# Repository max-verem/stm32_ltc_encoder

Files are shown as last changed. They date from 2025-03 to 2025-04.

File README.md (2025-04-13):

# stm32_ltc_encoder

This device used for decoding/encoding LTC (EBU Linear timecode) from/to VTRs or other sources.

Decoded Output sent to CDC serial. Encoding control cli available on second CDC serial.

## schematic

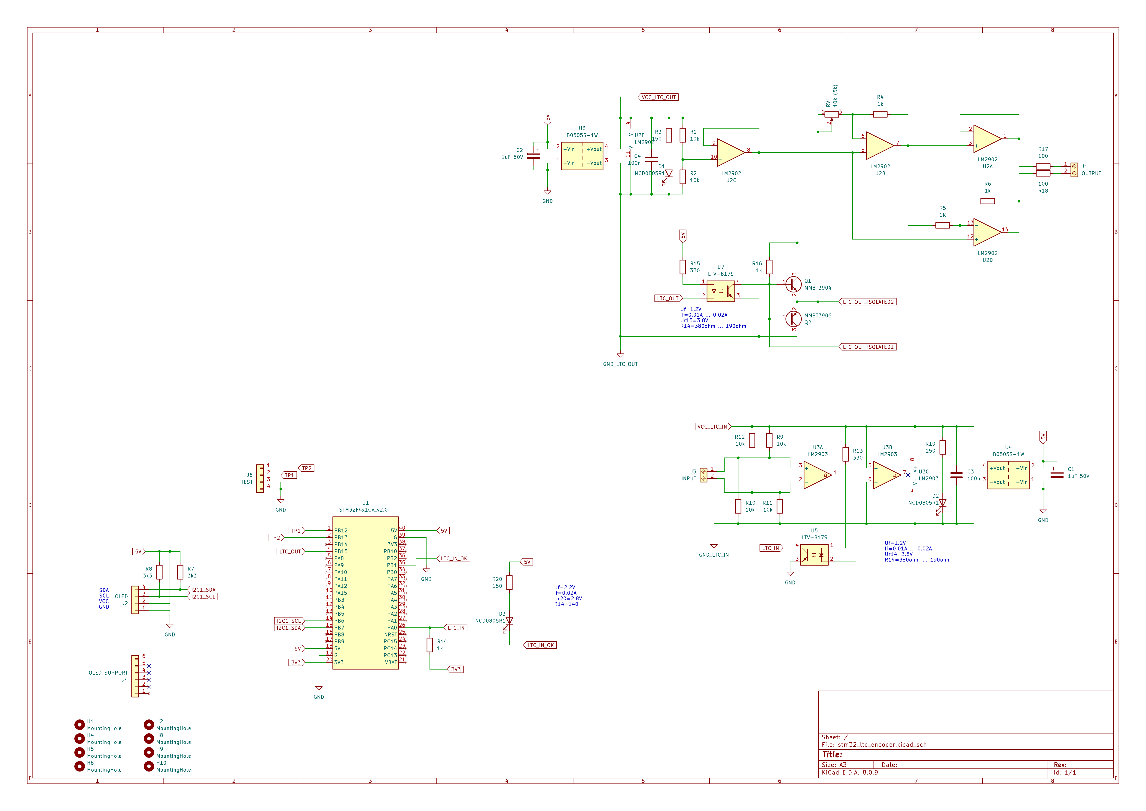
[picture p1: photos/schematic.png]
schematic


## photo

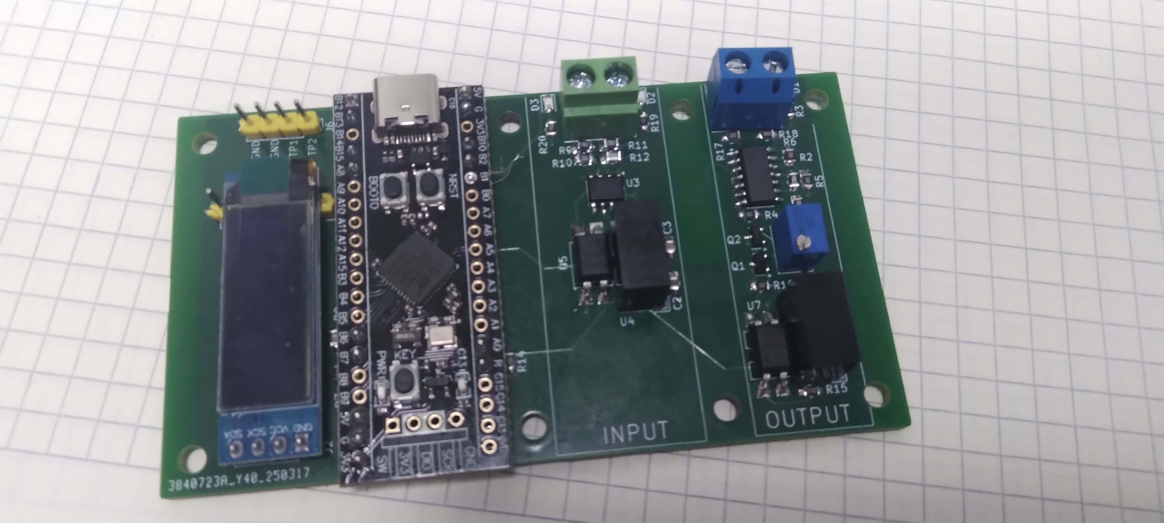
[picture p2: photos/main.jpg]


## encoding/generating LTC

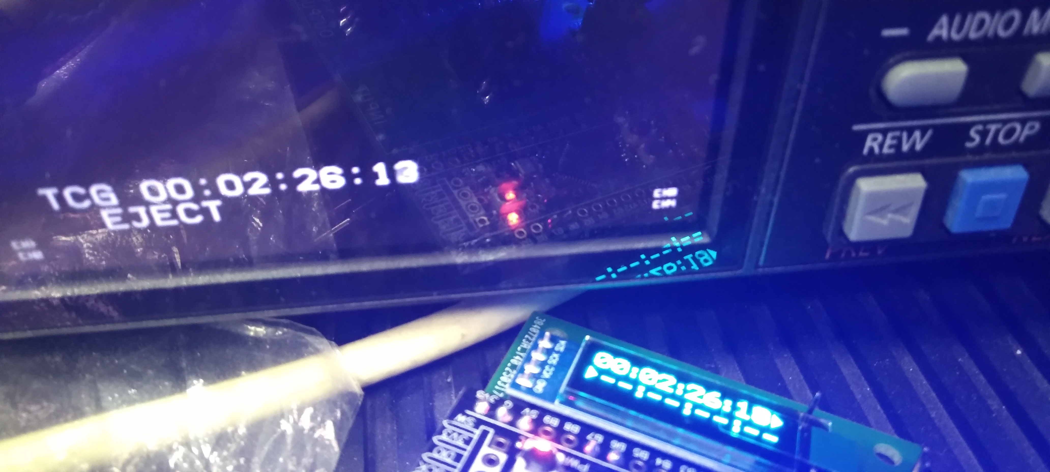
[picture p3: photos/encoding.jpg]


## decoding LTC

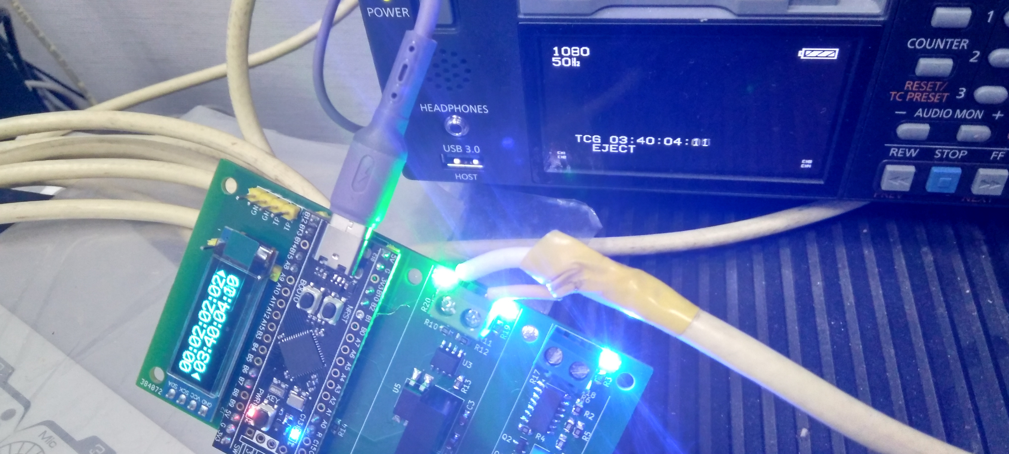
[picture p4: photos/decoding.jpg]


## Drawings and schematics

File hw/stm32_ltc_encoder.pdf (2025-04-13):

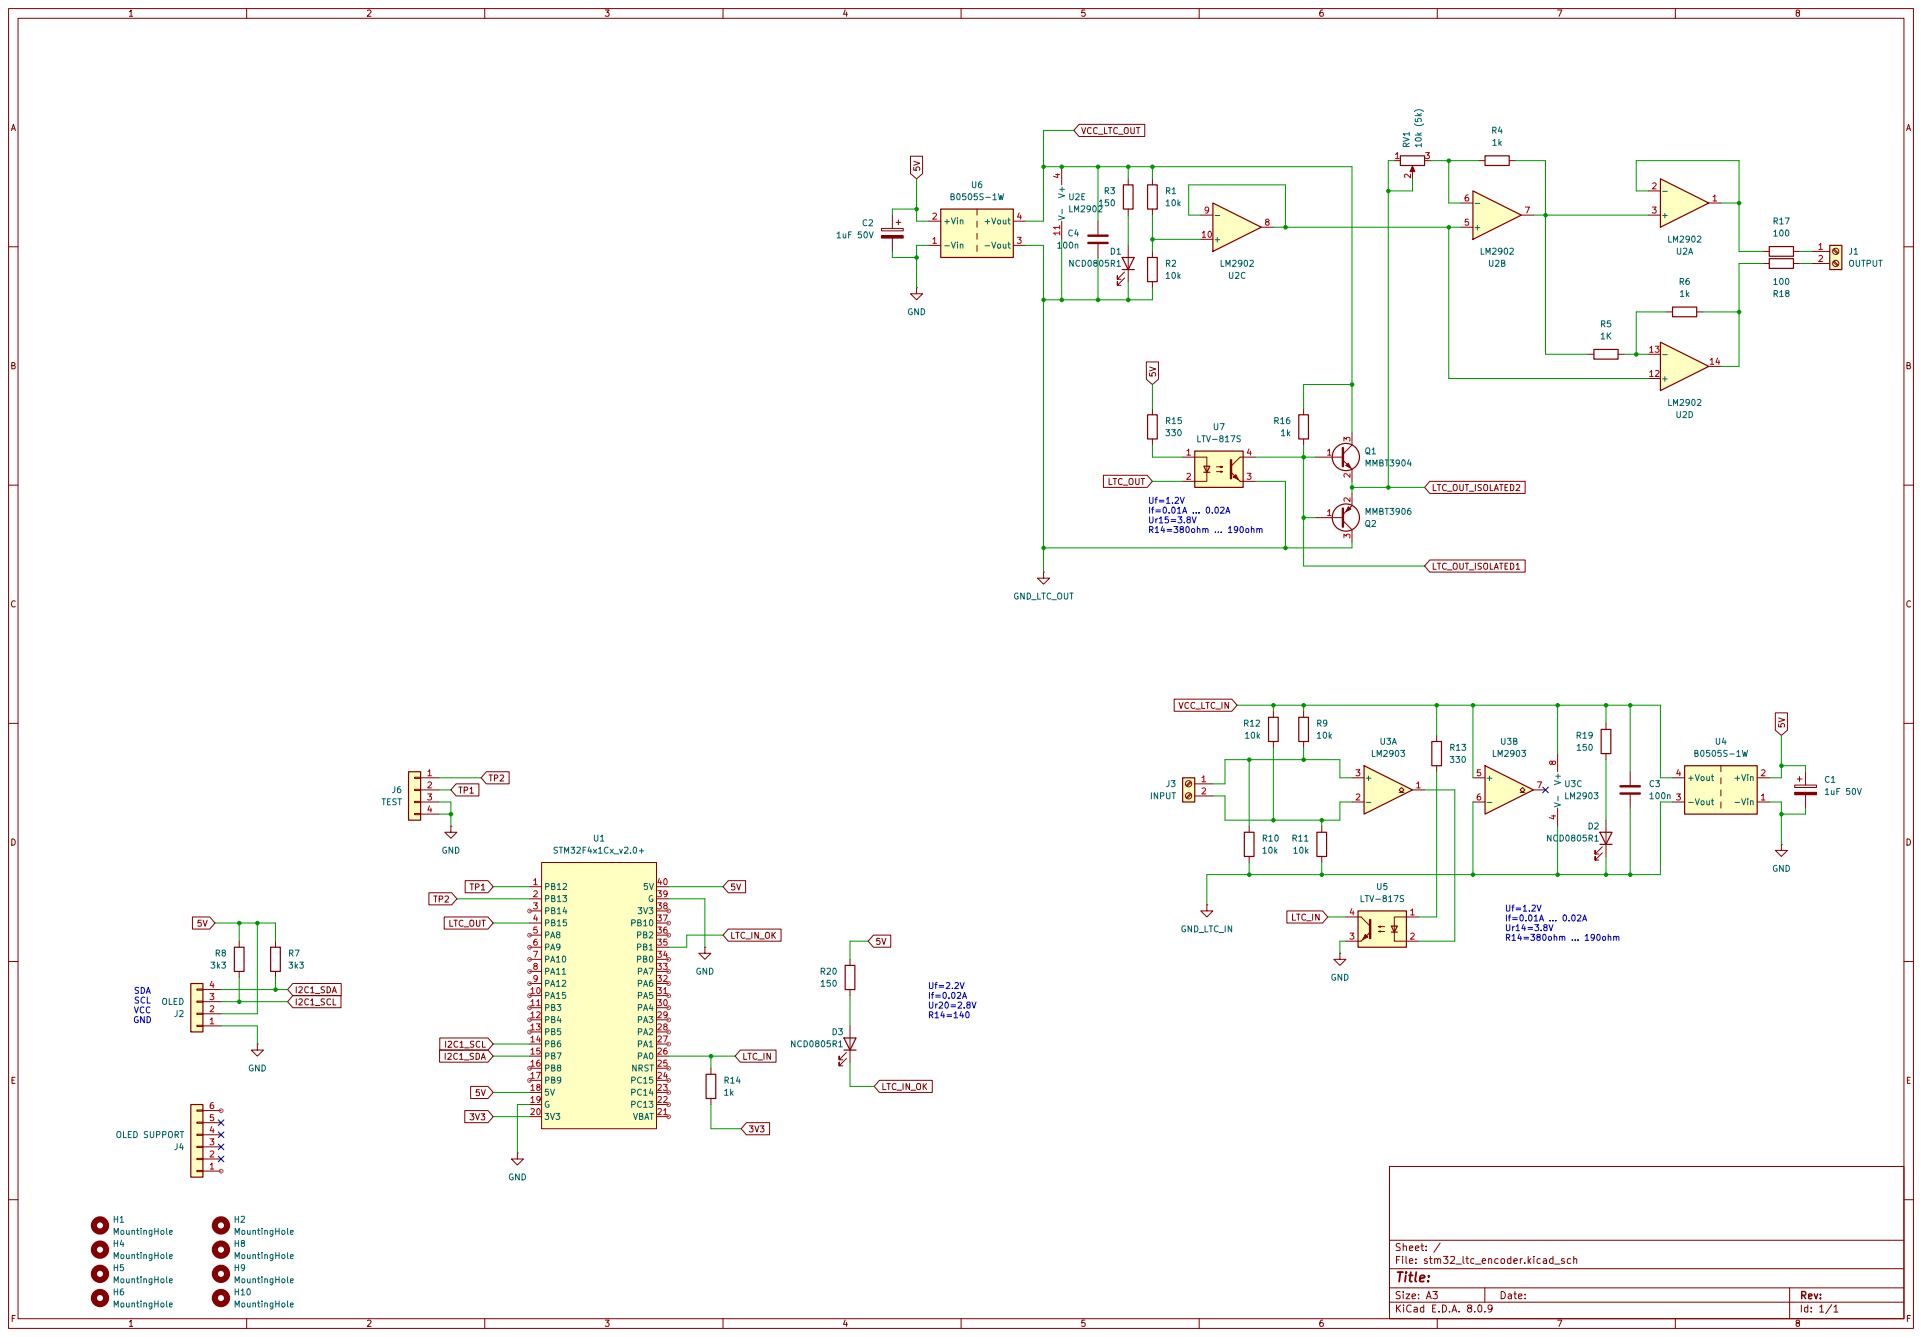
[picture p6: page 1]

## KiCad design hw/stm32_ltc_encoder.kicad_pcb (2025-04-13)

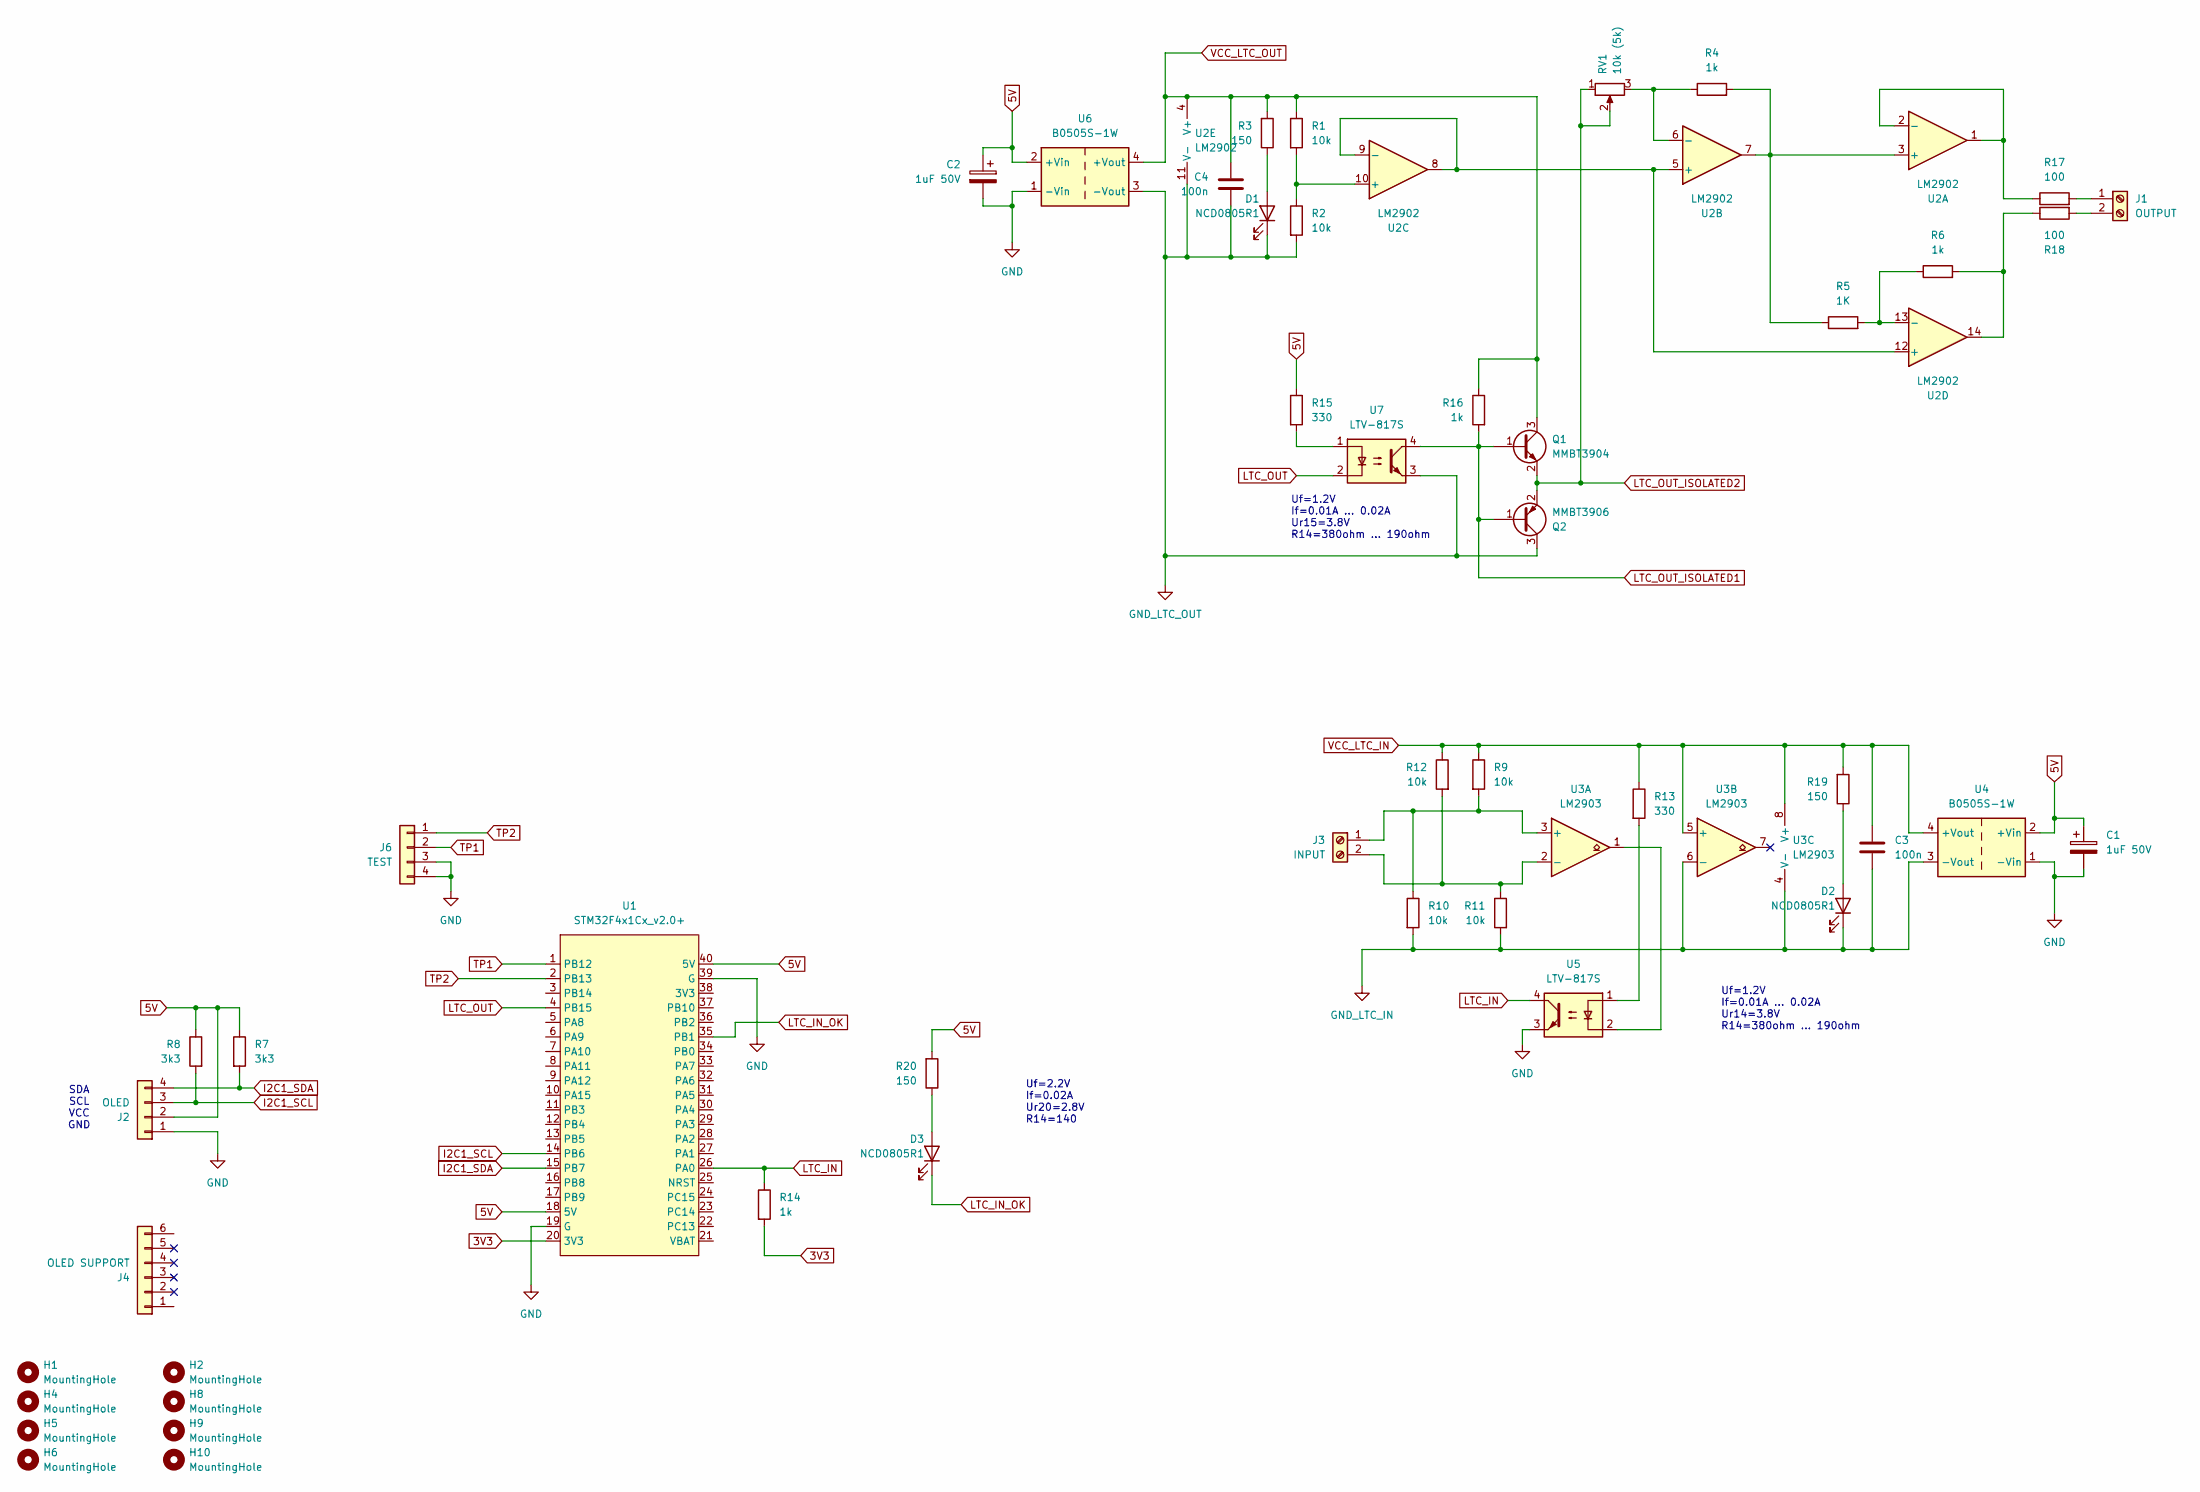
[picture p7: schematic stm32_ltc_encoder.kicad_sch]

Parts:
C1, C2: 1uF 50V; C_0805_2012Metric_Pad1.18x1.45mm_HandSolder
C3, C4: 100n; C_0805_2012Metric_Pad1.18x1.45mm_HandSolder
D1, D2, D3: NCD0805R1; LED_0805_2012Metric; JLCPCB Part # C84256
H1, H2, H4, H5, H6, H8, H9, H10: MountingHole; MountingHole_3.2mm_M3
J1: OUTPUT; TerminalBlock_bornier-2_P5.08mm; JLCPCB Part # C557646
J2: OLED; PinHeader_1x04_P2.54mm_Vertical
J3: INPUT; TerminalBlock_bornier-2_P5.08mm; JLCPCB Part # C557646
J4: OLED SUPPORT; PinHeader_1x06_P2.54mm_Vertical
J6: TEST; PinHeader_1x04_P2.54mm_Vertical
Q1: MMBT3904; SOT-23
Q2: MMBT3906; SOT-23
R1, R2, R9, R10, R11, R12: 10k; R_0805_2012Metric_Pad1.20x1.40mm_HandSolder
R3, R19, R20: 150; R_0805_2012Metric; JLCPCB Part # C17714
R4, R6, R14, R16: 1k; R_0805_2012Metric_Pad1.20x1.40mm_HandSolder
R5: 1K; R_0805_2012Metric_Pad1.20x1.40mm_HandSolder
R7, R8: 3k3; R_0805_2012Metric_Pad1.20x1.40mm_HandSolder
R13, R15: 330; R_0805_2012Metric_Pad1.20x1.40mm_HandSolder
R17, R18: 100; R_0805_2012Metric_Pad1.20x1.40mm_HandSolder
RV1: 10k (5k); Potentiometer_Bourns_3266W_Vertical
U1: STM32F4x1Cx_v2.0+; DIP-40_W15.24mm_LongPads
U2: LM2902; SOIC-14_3.9x8.7mm_P1.27mm
U3: LM2903; SOIC-8_3.9x4.9mm_P1.27mm
U4, U6: B0505S-1W; Converter_DCDC_TRACO_TME_03xxS_05xxS_12xxS_Single_THT
U5, U7: LTV-817S; SMDIP-4_W9.53mm

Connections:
3V3: R14.2, U1.20 (3V3)
5V: C1.1, C2.1, J2.2, R7.1, R8.1, R15.1, R20.2, U1.18 (5V), U1.40 (5V), U4.2 (+Vin), U6.2 (+Vin)
GND: C1.2, C2.2, J2.1, J6.3, J6.4, U1.19 (G), U1.39 (G), U4.1 (-Vin), U5.3, U6.1 (-Vin)
GND_LTC_IN: C3.2, D2.1 (K), R10.2, R11.2, U3.4 (V-), U3.6 (-), U4.3 (-Vout)
GND_LTC_OUT: C4.2, D1.1 (K), Q2.3 (C), R2.2, U2.11 (V-), U6.3 (-Vout), U7.3
I2C1_SCL: J2.3, R8.2, U1.14 (PB6)
I2C1_SDA: J2.4, R7.2, U1.15 (PB7)
LTC_IN: R14.1, U1.26 (PA0), U5.4
LTC_IN_OK: D3.1 (K), U1.35 (PB1)
LTC_OUT: U1.4 (PB15), U7.2
LTC_OUT_ISOLATED1: Q1.1 (B), Q2.1 (B), R16.2, U7.4
LTC_OUT_ISOLATED2: Q1.2 (E), Q2.2 (E), RV1.1, RV1.2
unnamed: D1.2 (A), R3.1
unnamed: D2.2 (A), R19.1
unnamed: D3.2 (A), R20.1
unnamed: J1.1, R17.2
unnamed: J1.2, R18.2
unnamed: J3.1, R9.2, R10.1, U3.3 (+)
unnamed: J3.2, R11.1, R12.2, U3.2 (-)
unnamed: R13.2, U5.1
unnamed: R15.2, U7.1
unnamed: R6.2, R18.1, U2.14
unnamed: R4.2, R5.1, U2.3 (+), U2.7
unnamed: R17.1, U2.1, U2.2 (-)
unnamed: U2.5 (+), U2.8, U2.9 (-), U2.12 (+)
unnamed: R4.1, RV1.3, U2.6 (-)
unnamed: R1.2, R2.1, U2.10 (+)
unnamed: R5.2, R6.1, U2.13 (-)
unnamed: U3.1, U5.2
TP1: J6.2, U1.1 (PB12)
TP2: J6.1, U1.2 (PB13)
VCC_LTC_IN: C3.1, R9.1, R12.1, R13.1, R19.2, U3.5 (+), U3.8 (V+), U4.4 (+Vout)
VCC_LTC_OUT: C4.1, Q1.3 (C), R1.1, R3.2, R16.1, U2.4 (V+), U6.4 (+Vout)

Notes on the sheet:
SDA SCL VCC GND
Uf=2.2V If=0.02A Ur20=2.8V R14=140
Uf=1.2V If=0.01A ... 0.02A Ur15=3.8V R14=380ohm ... 190ohm
Uf=1.2V If=0.01A ... 0.02A Ur14=3.8V R14=380ohm ... 190ohm

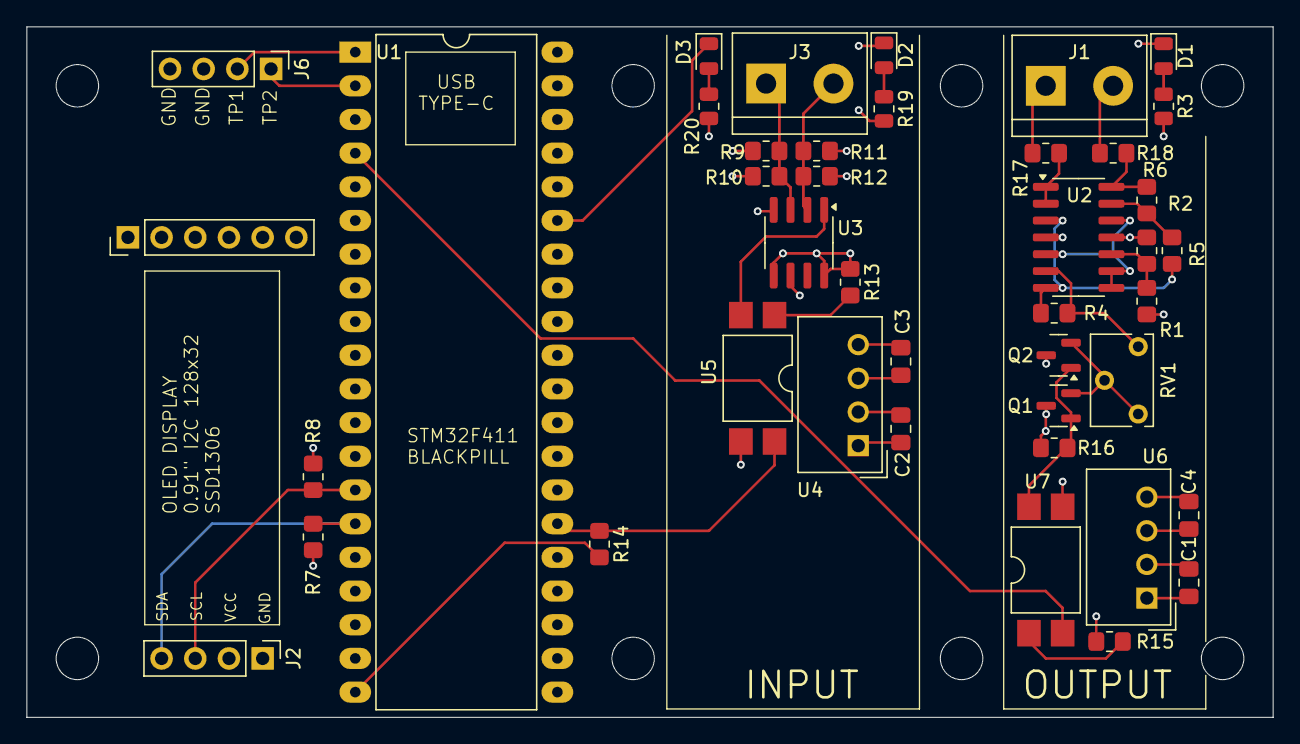
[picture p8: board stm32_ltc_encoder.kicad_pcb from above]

Board: 4 copper layers, 94.0 x 52.1 mm, 50 parts (0 on the bottom side), 33 nets.

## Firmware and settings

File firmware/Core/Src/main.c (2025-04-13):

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
/* Includes ------------------------------------------------------------------*/
#include "main.h"
#include "dma.h"
#include "i2c.h"
#include "tim.h"
#include "usb_otg.h"
#include "gpio.h"

/* USER CODE BEGIN Includes */
//#include <stdatomic.h>
#include "ltc_encoder.h"
#include "ltc_decoder.h"
#include "cli.h"
#include "SSD1306.h"
#include "font-12x16.h"

#include "usb_device.h"
#include "usbd_cdc_acm_if.h"
/* USER CODE END Includes */


/* USER CODE BEGIN PV */

SSD1306_DEF(oled1, hi2c1, SSD1306_I2C_ADDR, 32, 0);

/* USER CODE END PV */

void SystemClock_Config(void);
/* USER CODE BEGIN PFP */

uint32_t tc_bcd_normalize_test = 0;

/* USER CODE END PFP */

/* USER CODE BEGIN 0 */
#define TC_DISPLAY_UNKNOWN 	0xAAAAAAAA
#define TC_DISPLAY_NONE 	0xFFFFFFFF
uint32_t tc_in_display = TC_DISPLAY_UNKNOWN, tc_in_displayed = TC_DISPLAY_NONE, tc_out_displayed = TC_DISPLAY_NONE;

#define TIMER_A_DIV(DIV) if(!(timerA_cnt % DIV))
#define TIMER_A_DIV_BLINK_FAST 50
#define TIMER_A_DIV_BLINK_SLOW 500
volatile int timerA_cnt = 0;
static void timerA_cb(TIM_HandleTypeDef *htim)
{
	unsigned int now = HAL_GetTick();

	timerA_cnt++;

	/* blink fast it timecode detected */
	/* check if we should solid led if no timecode detected */
	if((ltc_last + 1000) < now)
	{
		// HAL_GPIO_WritePin(LED_GPIO_Port, LED_Pin, GPIO_PIN_RESET);
		tc_in_display = TC_DISPLAY_UNKNOWN;

		TIMER_A_DIV(TIMER_A_DIV_BLINK_SLOW)
			HAL_GPIO_TogglePin(LED_GPIO_Port, LED_Pin);

		HAL_GPIO_WritePin(LTC_IN_OK_GPIO_Port, LTC_IN_OK_Pin, GPIO_PIN_SET);
	}
	else
	{
		/* blink fast it timecode detected */
		TIMER_A_DIV(TIMER_A_DIV_BLINK_FAST)
			HAL_GPIO_TogglePin(LED_GPIO_Port, LED_Pin);

		HAL_GPIO_WritePin(LTC_IN_OK_GPIO_Port, LTC_IN_OK_Pin, GPIO_PIN_RESET);
	};

	SSD1306_refresh(&oled1);
};

extern USBD_HandleTypeDef hUsbDevice;

static volatile int cdc_ready[2] = {0};
static void ltc_decoder_callback(uint32_t tc_bcd, uint8_t *tc_str_data, uint32_t tc_str_len)
{
	tc_in_display = tc_bcd;
	if(cdc_ready[1])
		CDC_Transmit(1, tc_str_data, tc_str_len);
}

static uint32_t console_font_12x16_transposed[2 /* rows 8 pixels height */][16 /* glyphs */][3 /* 32-bits words width */];

static void console_font_12x16_transpose()
{
	int g;

	uint16_t G[16];

	for(g = 0; g < 14; g++)
	{
		int i, row, col;
		const uint8_t *g_src;

		/* copy to src */
		g_src = console_font_12x16 + g * 2 * 16;
		for(i = 0; i < 16; i++)
		{
			uint16_t l = g_src[2 * i + 0];
			uint16_t r = g_src[2 * i + 1];
			G[i] = l << 8 | r;
		}

		/* transpose */
		for(row = 0; row < 2; row++)
		{
			uint16_t m_src = 0x8000;
			uint8_t *g_dst = (uint8_t *)console_font_12x16_transposed[row][g];

			/* semicolon shift */
			if(g == 11) m_src >>= 1;
			/* arrow to right (for right corner) shift */
			if(g == 12) m_src >>= 1;
			/* arrow to right (for left corner) shift */
			if(g == 13) m_src >>= 3;

			for(col = 0; col < 12; col++, m_src >>= 1, g_dst++)
			{
				int h;
				uint8_t m_dst = 1, c = 0;

				for(h = 0; h < 8; h++, m_dst <<= 1)
					c |= G[row * 8 + h] & m_src ? m_dst : 0;

				*g_dst = c;
			}
		}
	}

};

static void oled_redraw(uint32_t bcd, int top_offset)
{
	int j, s;

	uint32_t
		*top = (uint32_t*)&oled1.fb[0 + top_offset][SSD1306_DATA_OFFSET],
		*bottom = (uint32_t*)&oled1.fb[1 + top_offset][SSD1306_DATA_OFFSET];

	for(j = 0, s = 28; j < 8; j++, s -= 4)
	{
		uint32_t g;

		/* out char */
		g = 13;
		if(j == 0 && top_offset)
		{
			*top =  console_font_12x16_transposed[0][g][0]; top++;
			*top =  console_font_12x16_transposed[0][g][1]; top++;
			*bottom =  console_font_12x16_transposed[1][g][0]; bottom++;
			*bottom =  console_font_12x16_transposed[1][g][1]; bottom++;
		}

		// find glyph index
		g = bcd >> s;
		g &= 0x0F;
		if(g > 10) g = 10;

		// copy glyph bitmap data
		*top =  console_font_12x16_transposed[0][g][0]; top++;
		*top =  console_font_12x16_transposed[0][g][1]; top++;
		*top =  console_font_12x16_transposed[0][g][2]; top++;
		*bottom =  console_font_12x16_transposed[1][g][0]; bottom++;
		*bottom =  console_font_12x16_transposed[1][g][1]; bottom++;
		*bottom =  console_font_12x16_transposed[1][g][2]; bottom++;

		/* semicolon */
		g = 11;
		if(j == 1 || j == 3 || j == 5)
		{
			*top =  console_font_12x16_transposed[0][g][0]; top++;
			*top =  console_font_12x16_transposed[0][g][1]; top++;
			*bottom =  console_font_12x16_transposed[1][g][0]; bottom++;
			*bottom =  console_font_12x16_transposed[1][g][1]; bottom++;
		}

		/* out char */
		g = 12;
		if(j == 7 && !top_offset)
		{
			*top =  console_font_12x16_transposed[0][g][0]; top++;
			*top =  console_font_12x16_transposed[0][g][1]; top++;
			*bottom =  console_font_12x16_transposed[1][g][0]; bottom++;
			*bottom =  console_font_12x16_transposed[1][g][1]; bottom++;
		}
	}
}

static void oled_idle()
{
	uint32_t mask;

	mask = 3;
	if(ltc_bcd_curr != tc_out_displayed && !(oled1.dirty & mask) && !(oled1.busy & mask))
	{
		oled_redraw(tc_out_displayed = ltc_bcd_curr, 0);

		// mark pages dirty
		oled1.dirty |= mask;

		return;
	}


	mask = 12;
	if(tc_in_display != tc_in_displayed && !(oled1.dirty & mask) && !(oled1.busy & mask))
	{
		oled_redraw(tc_in_displayed = tc_in_display, 2);

		// mark pages dirty
		oled1.dirty |= mask;

		return;
	}
}

extern USBD_HandleTypeDef hUsbDevice;
extern USBD_CDC_ACM_ItfTypeDef USBD_CDC_ACM_fops;
static USBD_CDC_ACM_ItfTypeDef _USBD_CDC_ACM_fops;
static int8_t _CDC_Init(uint8_t cdc_ch)
{
	int8_t r;

	r = _USBD_CDC_ACM_fops.Init(cdc_ch);

	cdc_ready[cdc_ch]++;

	return r;
}

static int8_t _CDC_Control(uint8_t cdc_ch, uint8_t cmd, uint8_t *pbuf, uint16_t length)
{
	int8_t r;

	r = _USBD_CDC_ACM_fops.Control(cdc_ch, cmd, pbuf, length);

	return r;
}

static int8_t _CDC_Receive(uint8_t cdc_ch, uint8_t *Buf, uint32_t *Len)
{
	if(!cdc_ch)
		cli_callback_recv_data(Buf, *Len);
	USBD_CDC_SetRxBuffer(cdc_ch, &hUsbDevice, &Buf[0]);
	USBD_CDC_ReceivePacket(cdc_ch, &hUsbDevice);
	return (USBD_OK);
}

static int8_t _CDC_TransmitCplt(uint8_t cdc_ch, uint8_t *Buf, uint32_t *Len, uint8_t epnum)
{
	if(!cdc_ch)
		cli_callback_sent_data(Buf, *Len);
	return (USBD_OK);
}

/* USER CODE END 0 */

/**
  * @brief  The application entry point.
  * @retval int
  */
int main(void)
{

  /* MCU Configuration--------------------------------------------------------*/

  /* Reset of all peripherals, Initializes the Flash interface and the Systick. */
  HAL_Init();

  /* USER CODE BEGIN Init */
  _USBD_CDC_ACM_fops = USBD_CDC_ACM_fops;
  USBD_CDC_ACM_fops.Init = _CDC_Init;
  USBD_CDC_ACM_fops.Control = _CDC_Control;
  USBD_CDC_ACM_fops.TransmitCplt = _CDC_TransmitCplt;
  USBD_CDC_ACM_fops.Receive = _CDC_Receive;
  /* USER CODE END Init */

  /* Configure the system clock */
  SystemClock_Config();

  /* Initialize all configured peripherals */
  MX_GPIO_Init();
  MX_DMA_Init();
  MX_TIM1_Init();
  MX_I2C1_Init();
  MX_TIM2_Init();
  MX_TIM3_Init();
  MX_USB_OTG_FS_PCD_Init();
  /* USER CODE BEGIN 2 */

  MX_USB_DEVICE_Init();

  // start generic timer
  HAL_TIM_RegisterCallback(&htim3, HAL_TIM_PERIOD_ELAPSED_CB_ID, timerA_cb);
  HAL_TIM_Base_Start_IT(&htim3);

  // ltc out init and run
  ltc_encoder_init(&htim1, LTC_OUT_GPIO_Port, LTC_OUT_Pin);

  // ltc in init and run
  ltc_decoder_init(&htim2);

  // setup and init oled display
  console_font_12x16_transpose();
  SSD1306_setup(&oled1);

  /* USER CODE END 2 */

  /* Infinite loop */
  /* USER CODE BEGIN WHILE */
  while (1)
  {
	ltc_encoder_idle();
	ltc_decoder_idle(ltc_decoder_callback);
    cli_idle();
    oled_idle();
    /* USER CODE END WHILE */

    /* USER CODE BEGIN 3 */
  }

  /* USER CODE END 3 */
}

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


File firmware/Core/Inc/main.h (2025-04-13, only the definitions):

#define LED_Pin GPIO_PIN_13
#define LED_GPIO_Port GPIOC
#define LTC_IN_OK_Pin GPIO_PIN_1
#define LTC_IN_OK_GPIO_Port GPIOB
#define TP1_Pin GPIO_PIN_12
#define TP1_GPIO_Port GPIOB
#define TP2_Pin GPIO_PIN_13
#define TP2_GPIO_Port GPIOB
#define LTC_OUT_Pin GPIO_PIN_15
#define LTC_OUT_GPIO_Port GPIOB
#define TIMER1_PRESCALER_RAW 48
#define TIMER1_PERIOD_RAW 250
#define TIMER1_PRESCALER (TIMER1_PRESCALER_RAW - 1)
#define TIMER1_PERIOD (TIMER1_PERIOD_RAW - 1)
#define TIMER3_PRESCALER_RAW 48
#define TIMER3_PERIOD_RAW 1000
#define TIMER3_PRESCALER (TIMER3_PRESCALER_RAW - 1)
#define TIMER3_PERIOD (TIMER3_PERIOD_RAW - 1)

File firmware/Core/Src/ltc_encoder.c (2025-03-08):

#include "ltc_encoder.h"

#define TP1
#ifdef TP1
#include "main.h"
#endif

/*

 	 80 bits per 25 fps - 2000 bits per seconds
 	 each bit encoded by two bits - 4000 half bits per second
 	 timer should be configured for 4000Hz

 */

#define LTC_BITS_LEN			80
#define LTC_32BITS_PER_OUT_BIT 	2
#define LTC_32BITS_WORDS		(LTC_BITS_LEN * LTC_32BITS_PER_OUT_BIT)
#define SYNC_WORD 0xBFFC // 1011 1111 1111 1100

volatile static uint32_t ltc_pin;
volatile static uint32_t LTC_OUT_BIT_HIGH;
volatile static uint32_t LTC_OUT_BIT_LOW;
static uint32_t ltc_out_buffer_bcd[2];
static uint32_t ltc_out_buffer_data[2 * LTC_32BITS_WORDS];
static uint32_t ltc_raw_buffer_data[3] = {0x1050006, 0x9030005, SYNC_WORD};
volatile uint32_t ltc_bcd_update = 0xFFFFFFFF, ltc_bcd_curr = 0;

static void ltc_out_buffer_fill(uint32_t* bits_buffer, int half_idx)
{
	int i, w_idx = half_idx ? LTC_32BITS_WORDS : 0;

	/*
	 * always starts with a rising edge at the beginning of bit 0
	 */
	int toggle = 1;

	for(i = 0; i < LTC_BITS_LEN; w_idx += 2, i++)
	{
		int idx = i / 32, bit = i % 32;
		if(bits_buffer[idx] & (1 << bit))
		{
			// bit '1'
			ltc_out_buffer_data[w_idx + 0] = toggle ? LTC_OUT_BIT_HIGH : LTC_OUT_BIT_LOW;
			toggle ^= 1;
			ltc_out_buffer_data[w_idx + 1] = toggle ? LTC_OUT_BIT_HIGH : LTC_OUT_BIT_LOW;
			toggle ^= 1;
		}
		else
		{
			// bit '0'
			ltc_out_buffer_data[w_idx + 0] =
		    ltc_out_buffer_data[w_idx + 1] = toggle ? LTC_OUT_BIT_HIGH : LTC_OUT_BIT_LOW;
			toggle ^= 1;
		}
	};
};

static uint32_t ltc_raw_zero_bits_cnt(uint32_t* bits_buffer)
{
	int r, i;

	for(r = 0, i = 0; i < LTC_BITS_LEN; i++)
	{
		int idx = i / 32, bit = i % 32;

		if(!(bits_buffer[idx] & (1 << bit)))
			r++;
	};

	return r;
};

static void ltc_raw_toggle_bit_59(uint32_t* bits_buffer)
{
	int z = ltc_raw_zero_bits_cnt(bits_buffer);
	if(z & 1)
		bits_buffer[1] ^= 1 << (59 - 32);
};

uint32_t tc_bcd_normalize(uint32_t tc_bcd)
{
    int i;

    register uint32_t
        digit_mask = 0x0000000F,
        comp_mask = 0x000000FF,
        digit_max = 0x0000000A,
        carry = 0x00000010,
        tc_max = 0x23595924;

    for(i = 0; i < 8; i++)
    {
    	register uint32_t digit = tc_bcd & digit_mask;

        if(digit >= digit_max)
        {
            digit -= digit_max;
            tc_bcd &= ~digit_mask;
            tc_bcd |= digit;
            tc_bcd += carry;
        };

        if(i & 1)
        {
            if((tc_bcd & comp_mask) > (tc_max & comp_mask))
            {
                tc_bcd &= ~comp_mask;
                tc_bcd += carry;
            };

            comp_mask <<= 8;
        }

        digit_mask <<= 4;
        digit_max <<= 4;
        carry <<= 4;
    };

    return tc_bcd;
};


void tc_bcd_to_ltc_raw(uint32_t tc_bcd, uint32_t *ltc_raw)
{
/*

BCD TIMECODE:

  | H | h | M | m | S | s | F | f |
  +---+---+---+---+---+---+---+---+
32| 28| 24| 20| 16| 12|  8|  4|  0|


LTC WORD 0:

  | _ | S | _ | s | _ | F | _ | f |
  +---+---+---+---+---+---+---+---+
32| 28| 24| 20| 16| 12|  8|  4|  0|

f [ 0] -> [ 0] = 0
F [ 4] -> [ 8] = 4
s [ 8] -> [16] = 8
S [12] -> [24] = 12

*/
	ltc_raw[0] =
//                   HhMmSsFf
//                   0S0s0F0f
		((tc_bcd & 0x0000f000) << 12) |
		((tc_bcd & 0x00000f00) << 8) |
		((tc_bcd & 0x000000f0) << 4) |
		((tc_bcd & 0x0000000f) << 0);

/*
LTC WORD 1:

  | _ | H | _ | h | _ | M | _ | m |
  +---+---+---+---+---+---+---+---+
32| 28| 24| 20| 16| 12|  8|  4|  0|

m [16] -> [ 0] = -16
M [20] -> [ 8] = -12
h [24] -> [16] =  -8
H [28] -> [24] =  -4

 */


	ltc_raw[1] =
//                   HhMmSsFf
//                   0H0h0M0m
		((tc_bcd & 0xf0000000) >> 4) |
		((tc_bcd & 0x0f000000) >> 8) |
		((tc_bcd & 0x00f00000) >> 12) |
		((tc_bcd & 0x000f0000) >> 16);

	ltc_raw_toggle_bit_59(ltc_raw);
};

static void ltc_new_frame(int half_idx)
{
	/* check if we requested to update timecode */
	if(ltc_bcd_update != 0xFFFFFFFF)
	{
		ltc_bcd_curr = ltc_bcd_update;
		ltc_bcd_update = 0xFFFFFFFF;
	}

	ltc_out_buffer_bcd[half_idx] = ltc_bcd_curr;

	/* inc tc counter */
	ltc_bcd_curr++;

	/* mormalize it value*/
	ltc_bcd_curr = tc_bcd_normalize(ltc_bcd_curr);
};

static void dma_cb_half(DMA_HandleTypeDef *hdma)
{
	ltc_new_frame(0);
};

static void dma_cb_full(DMA_HandleTypeDef *hdma)
{
	ltc_new_frame(1);
};

void ltc_encoder_idle()
{
/*
	Release mode - 60uS
	Debug mode - 230uS
 */

	if(ltc_out_buffer_bcd[0] != 0xFFFFFFFF)
	{
#ifdef TP1
	HAL_GPIO_WritePin(TP1_GPIO_Port, TP1_Pin, GPIO_PIN_SET);
#endif
		/* build raw LTC data */
		tc_bcd_to_ltc_raw(ltc_out_buffer_bcd[0], ltc_raw_buffer_data);

		/* decompose to bits out buffer */
		ltc_out_buffer_fill(ltc_raw_buffer_data, 0);

		/* mark as done */
		ltc_out_buffer_bcd[0] = 0xFFFFFFFF;

#ifdef TP1
	HAL_GPIO_WritePin(TP1_GPIO_Port, TP1_Pin, GPIO_PIN_RESET);
#endif
	};

	if(ltc_out_buffer_bcd[1] != 0xFFFFFFFF)
	{
#ifdef TP1
	HAL_GPIO_WritePin(TP1_GPIO_Port, TP1_Pin, GPIO_PIN_SET);
#endif
		/* build raw LTC data */
		tc_bcd_to_ltc_raw(ltc_out_buffer_bcd[1], ltc_raw_buffer_data);

		/* decompose to bits out buffer */
		ltc_out_buffer_fill(ltc_raw_buffer_data, 1);

		/* mark as done */
		ltc_out_buffer_bcd[1] = 0xFFFFFFFF;

#ifdef TP1
	HAL_GPIO_WritePin(TP1_GPIO_Port, TP1_Pin, GPIO_PIN_RESET);
#endif
	};
}

void ltc_encoder_init(TIM_HandleTypeDef* tim, GPIO_TypeDef *gpio, uint32_t pin)
{
	HAL_DMA_RegisterCallback(tim->hdma[TIM_DMA_ID_UPDATE], HAL_DMA_XFER_CPLT_CB_ID, dma_cb_full);
	HAL_DMA_RegisterCallback(tim->hdma[TIM_DMA_ID_UPDATE], HAL_DMA_XFER_HALFCPLT_CB_ID, dma_cb_half);
//	HAL_DMA_RegisterCallback(tim->hdma[TIM_DMA_ID_UPDATE], HAL_DMA_XFER_ERROR_CB_ID, dma_cb_error);
//	HAL_DMA_RegisterCallback(tim->hdma[TIM_DMA_ID_UPDATE], HAL_DMA_XFER_ABORT_CB_ID, dma_cb_abort);

	ltc_pin = pin;
	LTC_OUT_BIT_HIGH = ltc_pin << 16;
	LTC_OUT_BIT_LOW = ltc_pin << 0;
	ltc_new_frame(0);
	ltc_new_frame(1);

	HAL_DMA_Start_IT(
		tim->hdma[TIM_DMA_ID_UPDATE],
		(uint32_t)ltc_out_buffer_data,
		(uint32_t)&(gpio->BSRR), 2 * LTC_32BITS_WORDS);
	__HAL_TIM_ENABLE_DMA(tim, TIM_DMA_UPDATE ); //Enable the TIM Update DMA request
	__HAL_TIM_ENABLE(tim);                 //Enable the Peripheral
};

#if 0
  // bit 59 toggle test
  {
	  static uint32_t raw_ltc[3] = {0x1050006, 0x9030005, SYNC_WORD};
	  int z0, z1, z2, b59m = (1 << (59 - 32)), b59v0, b59v1, b59v2;

	  // initial state - calc zero bits
	  z0 = ltc_raw_zero_bits_cnt(raw_ltc);
	  b59v0 = (raw_ltc[1] & b59m) ? 1 : 0;

	  // corrupt
	  raw_ltc[1] ^= b59m;

	  // corrupted state - calc zero bits
	  z1 = ltc_raw_zero_bits_cnt(raw_ltc);
	  b59v1 = (raw_ltc[1] & b59m) ? 1 : 0;

	  // fix
	  ltc_raw_toggle_bit_59(raw_ltc);

	  // fixed state - calc zero bits
	  z2 = ltc_raw_zero_bits_cnt(raw_ltc);
	  b59v2 = (raw_ltc[1] & b59m) ? 1 : 0;

	  __BKPT();
  }
#endif

#if 0
  {
	  static uint32_t raw_ltc[3] = {0x1050006, 0x9030005, SYNC_WORD};
	  ltc_out_buffer_fill(raw_ltc, 0);
	  ltc_out_buffer_fill(raw_ltc, 1);
//	  __BKPT();
  }
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

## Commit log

2025-03-09 Add oled display support. Use AL94_USB_Composite composite device implementation
2025-03-09 Rework displaying IN/OUT timecodes
    [main.c]
2025-03-09 Add padding to framebuffer bank/row/line
2025-03-17 Main HW schematic/pcb added
    [stm32_ltc_encoder.kicad_pcb, stm32_ltc_encoder.kicad_sch]
2025-04-13 Finalize release
    [stm32_ltc_encoder.kicad_pcb, stm32_ltc_encoder.kicad_sch]

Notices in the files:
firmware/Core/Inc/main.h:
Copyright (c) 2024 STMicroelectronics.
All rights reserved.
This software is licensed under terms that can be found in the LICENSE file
